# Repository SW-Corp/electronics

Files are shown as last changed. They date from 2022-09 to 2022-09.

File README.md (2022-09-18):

# Stanowisko badawcze do analizy działania stacji uzdatniania wody
## Część mechaniczno-elektroniczna

To repozytorium jest zbiorem schematów, opisów i plików projektowych tworzących razem kompletną dokumentację części mechaniczno-elektronicznej stanowiska badawczego do analizy działania stacji uzdatniania wody.

## Pliki

W katalogu `PCB` znajdują się podkatalogi zawierające schematy płytek drukowanych używanych w projekcie.

Katalog `STL` zawiera pliki .stl wszystkich elementów wydrukowanych w 3D, tak, żeby możliwe było wydrukowanie kopii wybranego elementu gdy któryś z będących w użyciu zostanie uszkodzony.

Ponadto został również załączony opis instalacji elektrycznej, specyfikacje poszczególnych komponentów i schemat podłączenia elementów elektronicznych.

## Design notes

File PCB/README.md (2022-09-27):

# PCB

Wszystkie projekty płytek PCB są dostarczone w formacie .lay6, który jest obsługiwany przez dostępny za darmo program Sprint Layout. Wersja demo wystarczy do otworzenia plików projektowych.

[Link do pobrania (lub kupienia) programu](https://www.electronic-software-shop.com/sprint-layout-60.html?language=en)

Katalogi:

1. Sterownik pompy - płytka sterująca pracą pompy. W projekcie zostały użyte 4 egzemplarze, po jednym na każdą pompę. Użyte przekaźniki to HF3FF, zasilanie cewki 12V, maks. obciążalność styków 10A. Użyty tranzystor to BC548. Użyte rezystory to 4.7kOhm, 1.5kOhm oraz 3.3kOhm (każdy z nich został zaznaczony w odpowiednim miejscu na schemacie).
	- "Sterownik pompy v2.lay6" - wersja nieaktualna. Została załączona do dokumentacji ze względu na to, że jest to wersja użyta w projekcie. Posiada błąd polegający na błędnym poprowadzeniu ścieżki do dzielnika napięcia 12V-5V. Konieczne jest wlutowanie rezystora 3.3kOhm *przed* rezystorem 4.7kOhm.
	- "Sterownik pompy v2 6x.lay6" - panel 6 płytek sterownika w wersji 2. Projekt służący przyspieszeniu produkcji większej ilości płytek.
	- "Sterownik pompy v3.lay6" - najnowsza wersja z poprawionym błędem dzielnika napięcia.

2. Sterownik zaworów - płytka sterująca pracą trzech elektrozaworów. Przekaźniki: HF3FF, 12V, max. 10A.
	- "Sterownik zaworow spustowych_v3.lay6"
	- "Sterownik zaworow spustowych_v3 2x.lay6" - panel z dwoma płytkami w celu szybszej produkcji PCB

3. Płyta główna - największa płytka w systemie odpowiedzialna za sterowanie urządzeniami i raportowanie stanu stacji. Stanowi łącznik pomiędzy warstwą sprzętową a oprogramowaniem na Raspberry Pi. Na płytce znajduje się 7 gniazd na mierniki napięcia i natężenia prądu `INA219` oraz 5 gniazd na czujniki ciśnienia `BMP280` (komunikacja z użyciem I2C). Ze względu na specyfikę tych czujników konieczne okazało się użycie multipleksera I2C (`TCA9548A`, adres `0x70`) dzięki któremu możliwe jest podłączenie do 8 urządzeń mających ten sam adres I2C. Na pierwszym złączu od lewej został podłączony również referencyjny czujnik ciśnienia ze zmienionym adresem (`0x77`). Pozostałe czujniki operują z użyciem domyślnego adresu I2C, tj. `0x76` dla BMP280.
    - "PlytaGlownaV2.lay6" - główny plik projektowy

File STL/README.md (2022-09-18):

# Pliki STL

Wydruki wykonane zostały z materiału PLA. Wypełnienie 20%, brak podpór, dysza 0.4mm.

- BMP280 - obudowa dla czujnika ciśnienia BMP280, służącego do pomiaru wysokości poziomu cieczy poprzez pomiar sumy ciśnienia atmosferycznego i ciśnienia hydrostatycznego wytwarzanego przez słup wody w zbiorniku. Należy zwrócić szczególną uwagę na wykonanie czujnika - obudowa musi zostać wydrukowana na drukarce drukującej żywicą (SLA/DLP), na przykład Anycubic Photon. Jest to jedyny wydruk tego typu, pozostałe mogą być drukowane na standardowych drukarkach FDM.
- BMPCase - obudowa dla czujnika ciśnienia BMP280 służącego jako czujnik referencyjny mierzący ciśnienie atmosferyczne.
- PowerAdapter - obudowa głównego zasilacza 12V 10A
- PowerButtonCover - obudowa wyłącznika głównego która osłania go od tyłu - zapobiega przypadkowemu kontaktowi z 230V
- PressureSensorCover - obudowa przykrywająca czujniki ciśnienia i stabilizująca ich przyleganie do płyty
- PumpHolder - uchwyt mocujący pompy. Wersja `v4` to mocowanie trzech pomp, natomiast wersja `v5` to mocowanie pompy pod ostatnim zbiornikiem
- SwitchPlate - projekt panelu z przełącznikami na przedniej płycie
- Washer12x8 - podkładka pozwalająca zamocować wyłącznik pływakowy na otworze ostatniego zbiornika
- WaterboxHolder - poziome poprzeczki służące do trzymania dwóch dużych zbiorników w poziomie
- WaterHoseHolder - uchwyty trzymające węże z wodą, zarówno te o średnicy 12mm i 8mm. Projekt 8mm_High to uchwyt węża idącego z ostatniej pompy (P4) do pierwszego zbiornika.
- WaterPipeHolder - uchwyty trzymające węże wchodzące do zbiorników. Uwaga: uchwyt dla ostatniego zbiornika jest inny niż dla pierwszego. Jest on przystosowany do montażu czujnika ciśnienia.

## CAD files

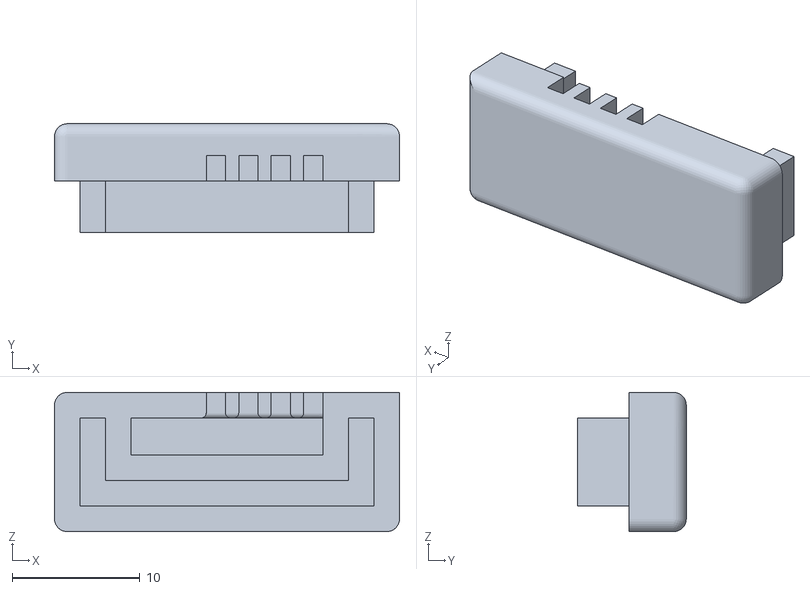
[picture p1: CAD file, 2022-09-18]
STL/BMP280/BMP280-BOX-HAT-V2.stl
27.0 x 8.50 x 10.9

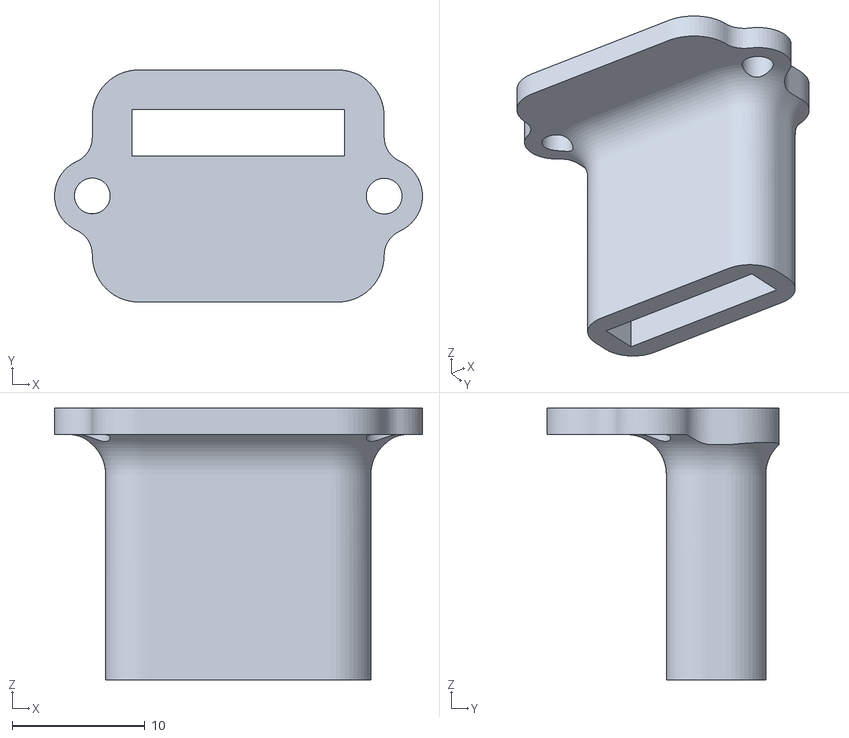
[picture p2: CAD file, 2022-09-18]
STL/BMPCase/Body.stl
27.7 x 17.5 x 20.5

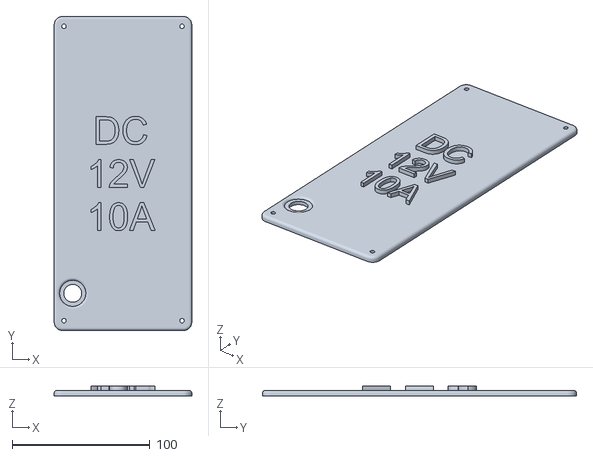
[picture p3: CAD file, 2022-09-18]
STL/PowerAdapter/Cover.stl
100.0 x 228.0 x 7.00

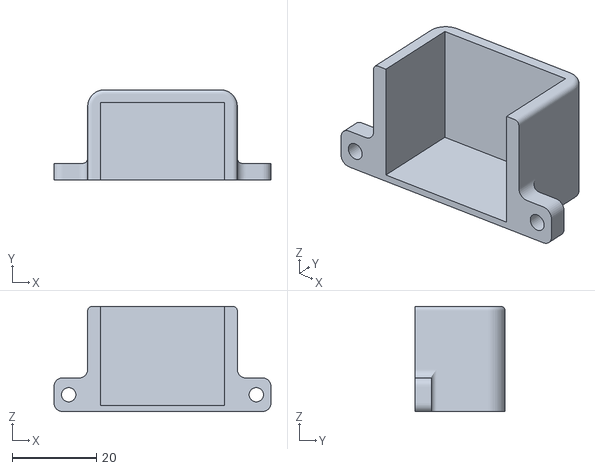
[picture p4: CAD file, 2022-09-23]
STL/PowerButtonCover/POWERBTN_COVER_v2.stl
51.6 x 21.5 x 25.0

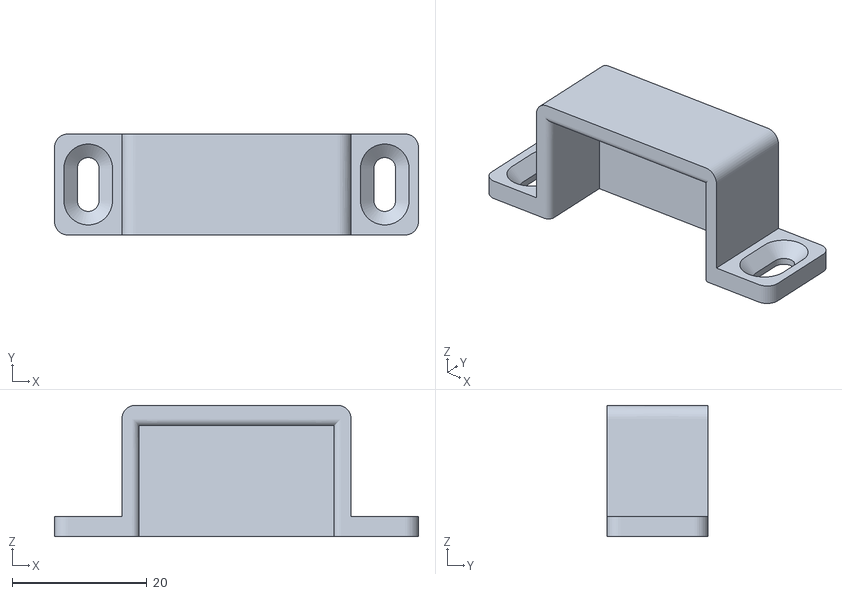
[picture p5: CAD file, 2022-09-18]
STL/PressureSensorCover/PressureSensorCoverTest v3.stl
54.0 x 15.0 x 19.5

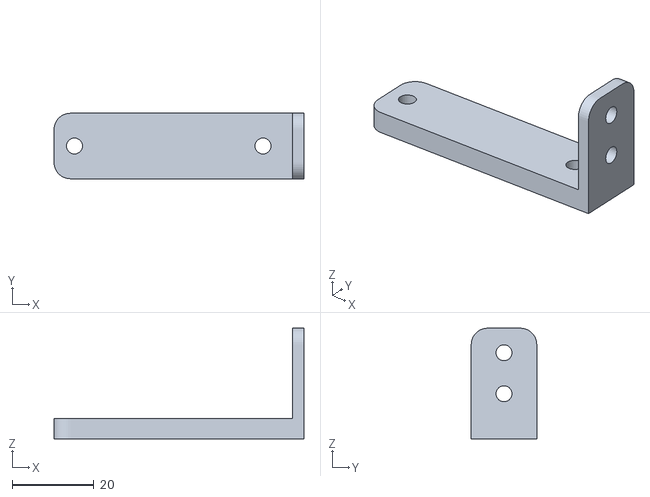
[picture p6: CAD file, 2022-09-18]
STL/PumpHolder/v5/PumpHolderV5.stl
61.0 x 16.0 x 27.0

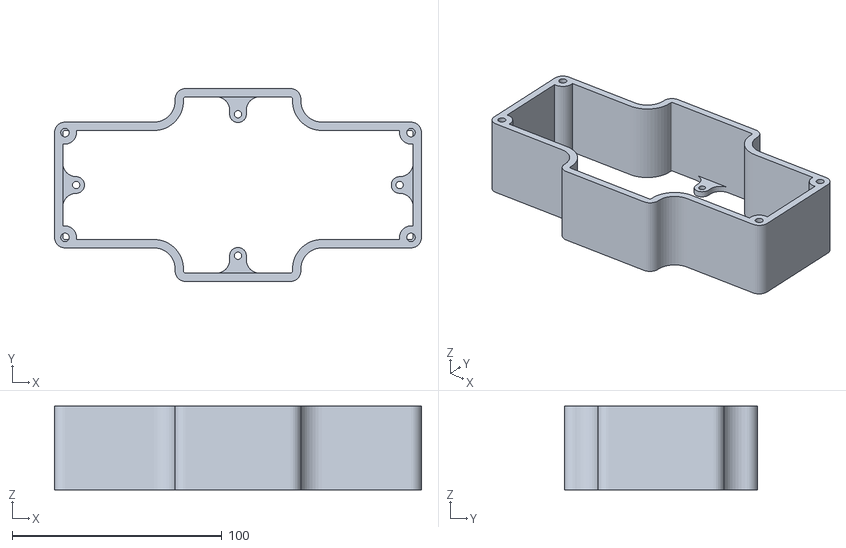
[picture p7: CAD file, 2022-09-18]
STL/SwitchPlate/SwitchPlate_BOX.stl
175.0 x 92.0 x 40.0

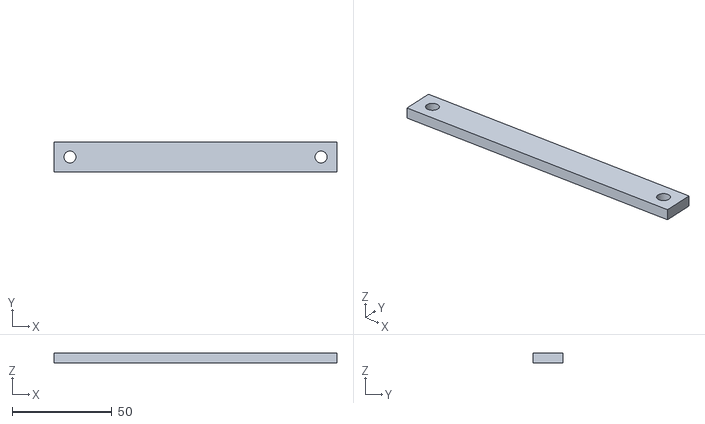
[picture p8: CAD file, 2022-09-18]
STL/WaterboxHolder/v1/WaterboxHolder.stl
142.0 x 15.0 x 5.00

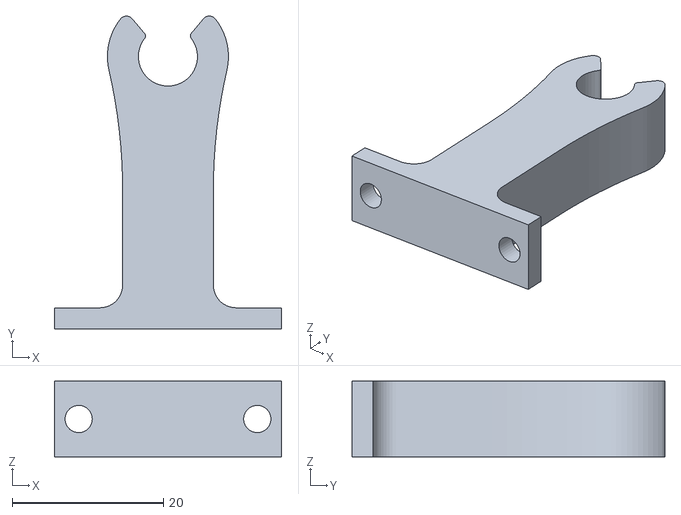
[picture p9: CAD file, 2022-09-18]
STL/WaterHoseHolder/8mm_High/v1/WaterhoseHolder8mm_High.stl
30.0 x 41.4 x 10.0

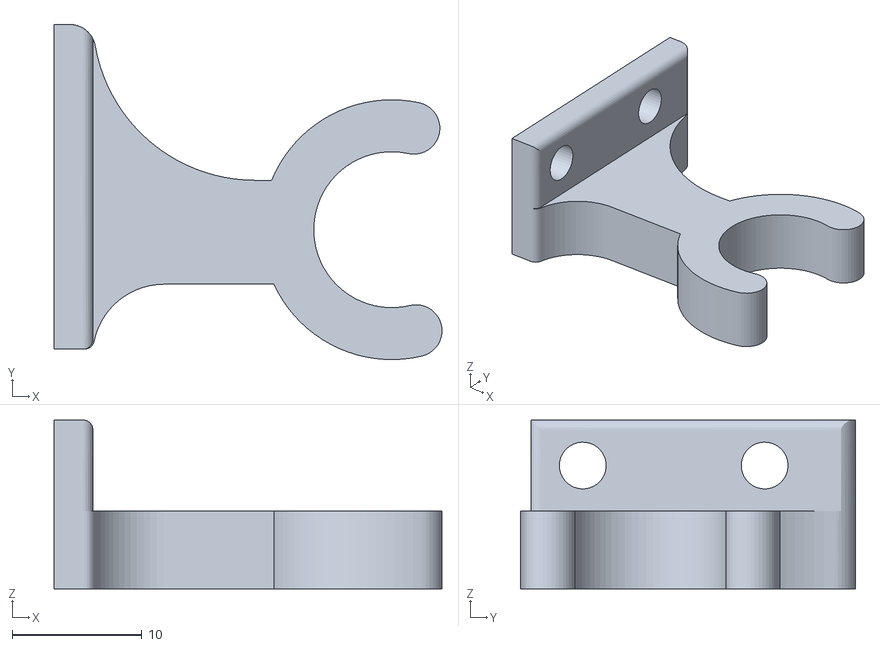
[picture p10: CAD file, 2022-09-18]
STL/WaterHoseHolder/v5/WaterhoseHolder12mmV5stl.stl
29.9 x 25.8 x 13.0

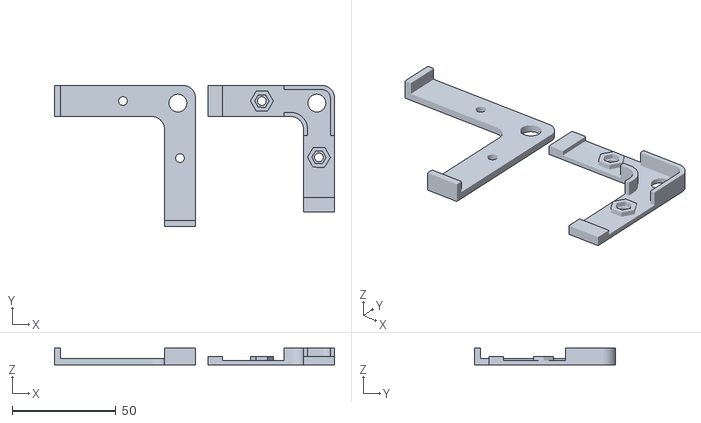
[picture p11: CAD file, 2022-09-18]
STL/WaterPipeHolder/Angular/WaterPipeHolder v1.stl
135.0 x 68.0 x 8.00

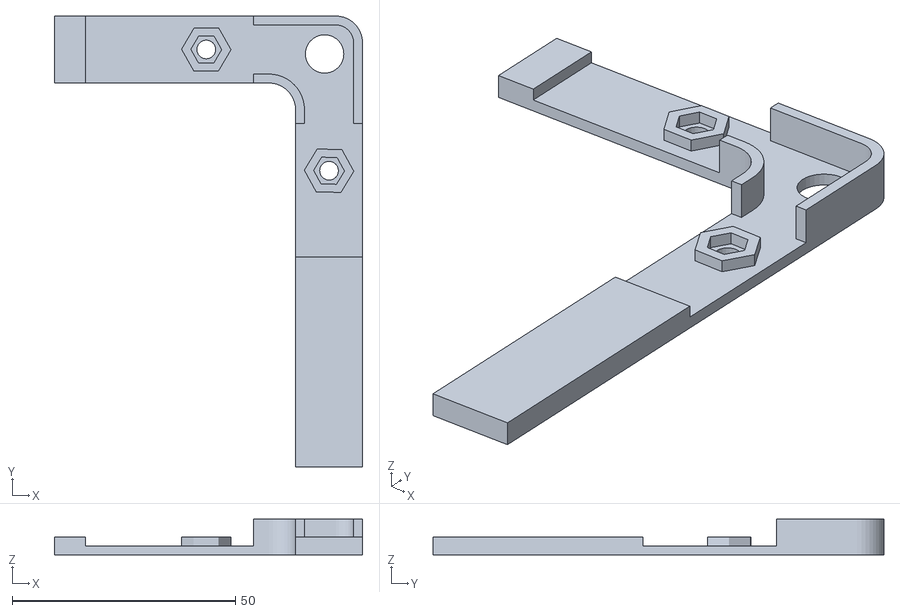
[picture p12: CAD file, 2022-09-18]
STL/WaterPipeHolder/Big/Bottom.stl
69.0 x 101.0 x 8.00

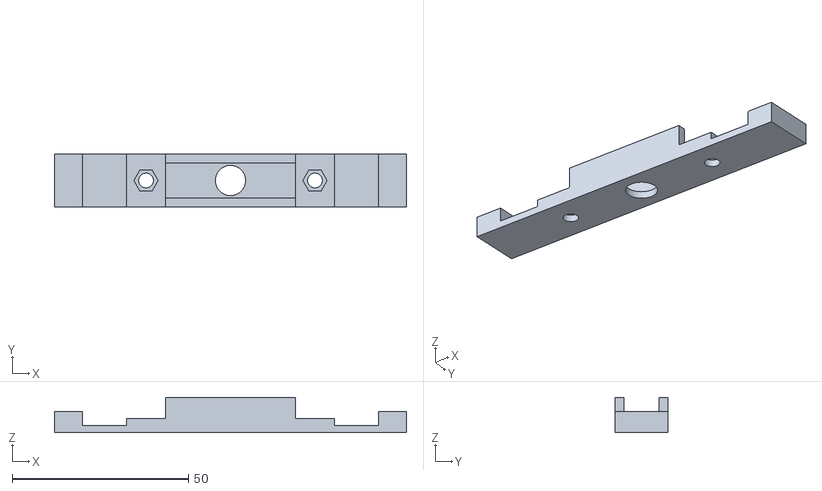
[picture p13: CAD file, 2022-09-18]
STL/WaterPipeHolder/Middle/Bottom.stl
100.0 x 15.0 x 10.0

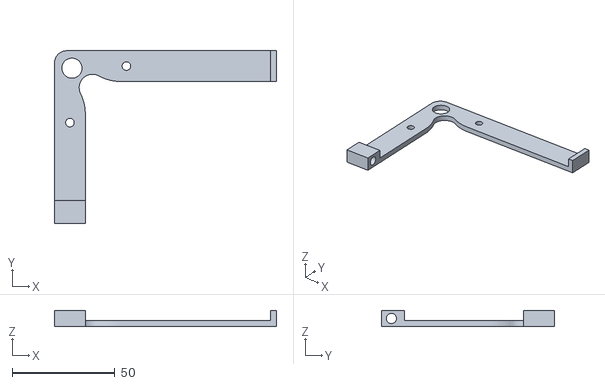
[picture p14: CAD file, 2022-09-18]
STL/WaterPipeHolder/WithSensor/Top.stl
108.0 x 84.0 x 8.00

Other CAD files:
STL/BMP280/BMP280-BOX-BODY-V2.stl
STL/BMPCase/Cover.stl
STL/PowerAdapter/Body.stl
STL/SwitchPlate/SwitchPlate_deep.stl
STL/PowerButtonCover/POWERBTN_COVER_v1.stl
STL/PumpHolder/v4/PumpHolderV4_v2.stl
STL/Washer12x8/Washer12x8.stl
STL/WaterPipeHolder/Big/Top.stl
STL/WaterPipeHolder/Middle/Mid.stl
STL/WaterPipeHolder/Middle/Top.stl
STL/WaterPipeHolder/WithSensor/Bottom.stl

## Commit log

2022-09-18 PCB and STL
    [BMP280-BOX-BODY-V2.stl, BMP280-BOX-HAT-V2.stl, Body.stl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]
2022-09-23 Power Button Cover v2
    [POWERBTN_COVER_v1.stl, POWERBTN_COVER_v2.stl]
